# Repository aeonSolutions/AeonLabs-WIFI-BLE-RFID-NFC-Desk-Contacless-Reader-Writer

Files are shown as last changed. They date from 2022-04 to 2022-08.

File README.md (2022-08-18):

# AeonLabs WIFI BLE RFID NFC Desk Contacless Reader Writer
 This repo contains the KiCad files for the  AeonLabs WIFI BLE RFID NFC Desk Contactless Reader Writer. This PCB adds WiFi and BLE capabilities to a OEM RFID NFC reader.
Features a RGB LED and a Buzzer and is designed to be mounted on existing commercial RFID NFC reader enclosures such as the one found [here](https://s.click.aliexpress.com/e/_9wRPxz) and [here](https://www.aliexpress.com/item/1005003803301443.html?spm=a2g0o.order_list.0.0.69ba1802ydCE38)

This PCB is best suited for home automation or commercial uses for #attendances #management at a factories or offices.

*Don't forget to LIKE , SHARE and subscribe the free whatsApp group* and if you liked this PCB consider buying me a cup of coffee. Links below.




### Status
  Running. Barcode & QRcode ; RFID waiting to be tested.

If you already tested this PCB send me a message. Thank you

## Revisions
- revision 3.1
  - Added Barcode & QR code wireless receiver for handheld scanners
  -  
- revision 2.3.1
  - Design and component placement corrections 

PCB fabrication of June 2022 (reviision 3.1) was sponsored by [PCBWay](www.pcbway.com)

## Liked it ? Get a Free PCB for yourself
Send me your Device or hardware and i will design a custom PCB for it. Free of charge. Contact-me on WhatsApp or email for more info. 

|  | *Don't forget to **LIKE** , **SHARE** and **subscribe** the free chat groups* and if you downloaded one of AeonLabs's PCBs consider sponsor  any open hardware project with a donation or a cup of coffee. Links on the top, right side pane and below. |
|---|---|

<br />
<br />

## Q&A WhatsApp/Telegram Groups
|  | Subscribe to the WhatsApp or Telegram channel to get latest information about any of this KiCad projects and get help. Or simply like this kind of projects and want to stay updated with the latest research ideas and prototypes during the day and week.   |
|---|---|

<br />
<br />
<br />

## Youtube Channel
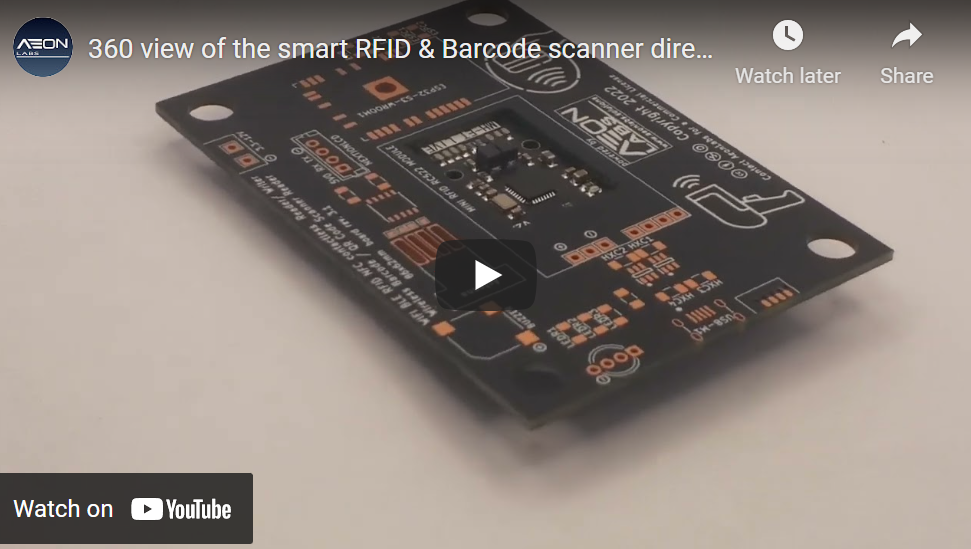
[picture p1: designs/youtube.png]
|  | Subscribe to my Youtube channel for PCB assembly instruction or any other related to Artificial Intelligence, Smart devices and robotics. Link to the channel [here](https://www.youtube.com/channel/UCAewCBpMRPGCyFc1ET5CHJw). My most recent video is .... |
|---|---|

## Fully assembled PCB
Alternatively, and if you do not want to build a PCB by yourself and like to buy one, you can do it here:

(https://www.tindie.com/stores/aeonlabs/)

The price will be around 30eur plus postage fees.
(I will also deliver the assembled PCB with all the components in place at a fair aditonal cost).

This PCB is a #direct fit #replacement of the one found on the internet at sale. For example here: https://s.click.aliexpress.com/e/_9wRPxz

#### Be supportive of my dedication and work towards technology education and buy me a coffee. Link below.

(https://www.youtube.com/watch?v=LmpYdi8Umxo)

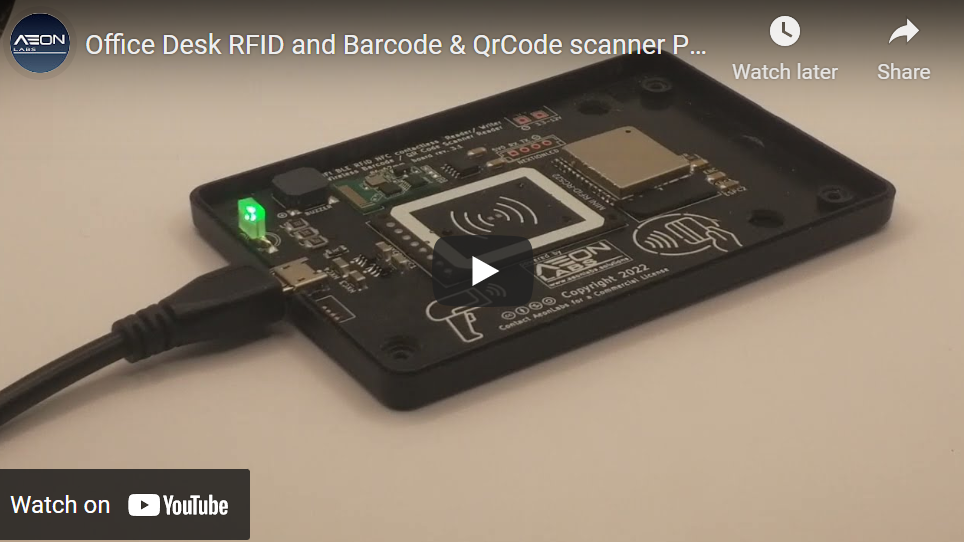
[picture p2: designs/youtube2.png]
(https://www.youtube.com/watch?v=fLvnoaH_I7A)


________________________________________________________________________________________________________________
## [Go back to main catalogue page](https://github.com/aeonSolutions/PCB-Prototyping-Catalogue)
________________________________________________________________________________________________________________

## PCB Parts list
- DC2DC converter HX4002B x2 : https://s.click.aliexpress.com/e/_Ak7IPx
- Capacitor 100nF SMD 1206 : https://s.click.aliexpress.com/e/_AVdmzr
- Capacitor 2.2uF SMD 1206 : https://s.click.aliexpress.com/e/_AVdmzr
- Resistor SMD 1206 330R x3 : https://s.click.aliexpress.com/e/_A7OXrR
- ESP32 WROOM32 x1 : https://s.click.aliexpress.com/e/_AF7N6l
- Buzzer x1: https://s.click.aliexpress.com/e/_AF7N6l
- LED RGB x1: https://s.click.aliexpress.com/e/_AccXHT
- RFID RC522 x1 (optional) : https://s.click.aliexpress.com/e/_Am0LAH

## Firmware Download 
one can use the PCB in the repository [AeonLabs-MCU-Burner-USB-to-UART-TTL](https://github.com/aeonSolutions/AeonLabs-MCU-Burner-USB-to-UART-TTL) to program the ESP32 WROOM32 MCU on this PCB.

______________________________________________________________________________________________________________________________

______________________________________________________________________________________________________________________________
### PCB Fabrication
(https://www.allpcb.com/?Mb_InviteId=79483)
(https://www.pcbway.com/setinvite.aspx?inviteid=572526)

<br />
<br />
<br />

______________________________________________________________________________________________________________________________
### License
2022 Creative Commons Attribution-NonCommercial-ShareAlike 4.0 International

https://creativecommons.org/licenses/by-nc-sa/4.0/

______________________________________________________________________________________________________________________________

<br />
<br />

### Be supportive of my dedication and work towards technology education and buy me a cup of coffee
Buy me a cup of coffee, a slice of pizza or a book to help me study, eat and think new PCB design files.

[](https://www.buymeacoffee.com/migueltomas)

<br />
<br />

### Make a donation on Paypal
Make a donation on paypal and get a TAX refund*.

(http://paypal.me/mtpsilva)

### Support all these open hardware projects and become a patreon  
Liked any of my PCB KiCad Designs? Help and Support my open work to all by becomming a LDAD Patreon.
In return I will give a free PCB design in KiCad to all patreon supporters. To learn more go to patreon.com. Link below.

(https://www.patreon.com/ldad)

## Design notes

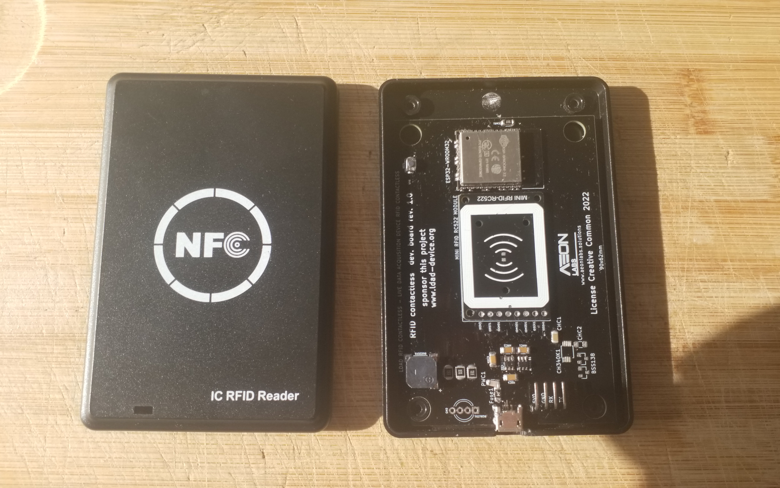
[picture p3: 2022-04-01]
designs/pcb_case.jpg

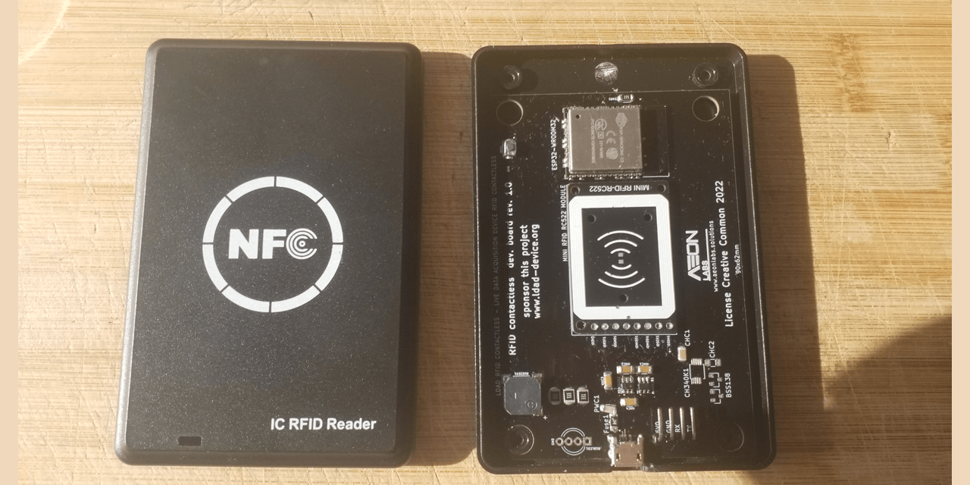
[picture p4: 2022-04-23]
designs/pcb_compressed.png

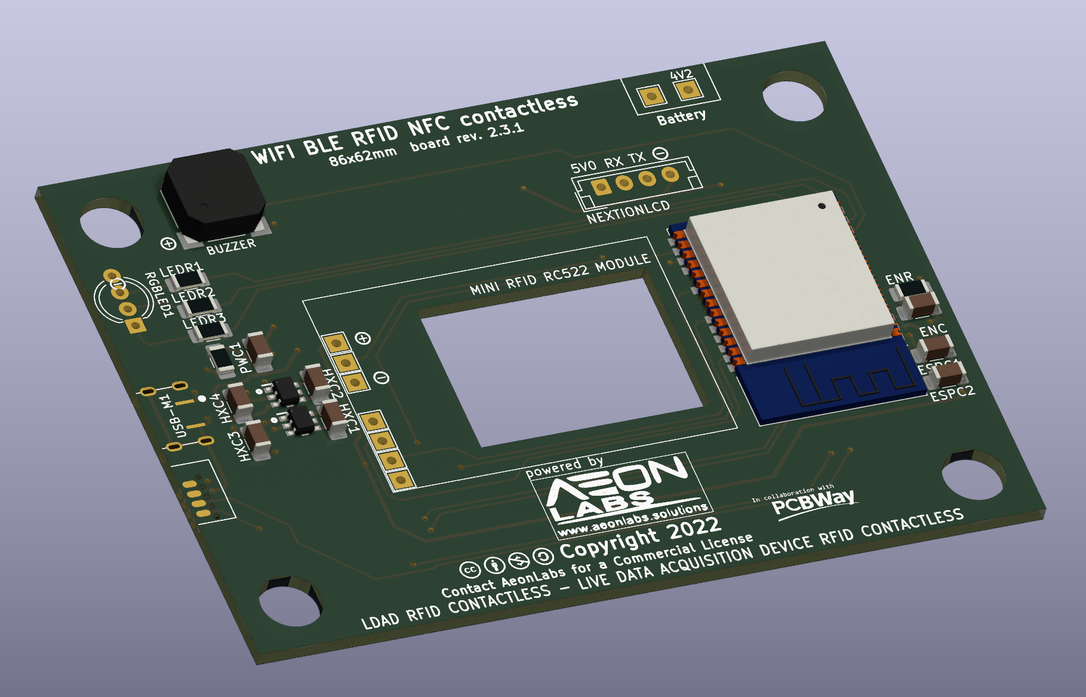
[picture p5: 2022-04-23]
designs/pcb_front.png

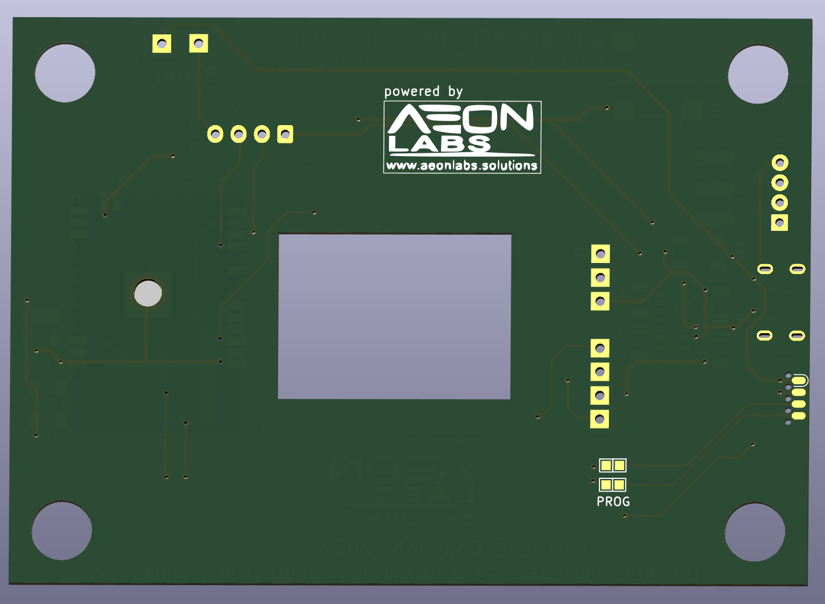
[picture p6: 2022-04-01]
designs/pcb_back.png

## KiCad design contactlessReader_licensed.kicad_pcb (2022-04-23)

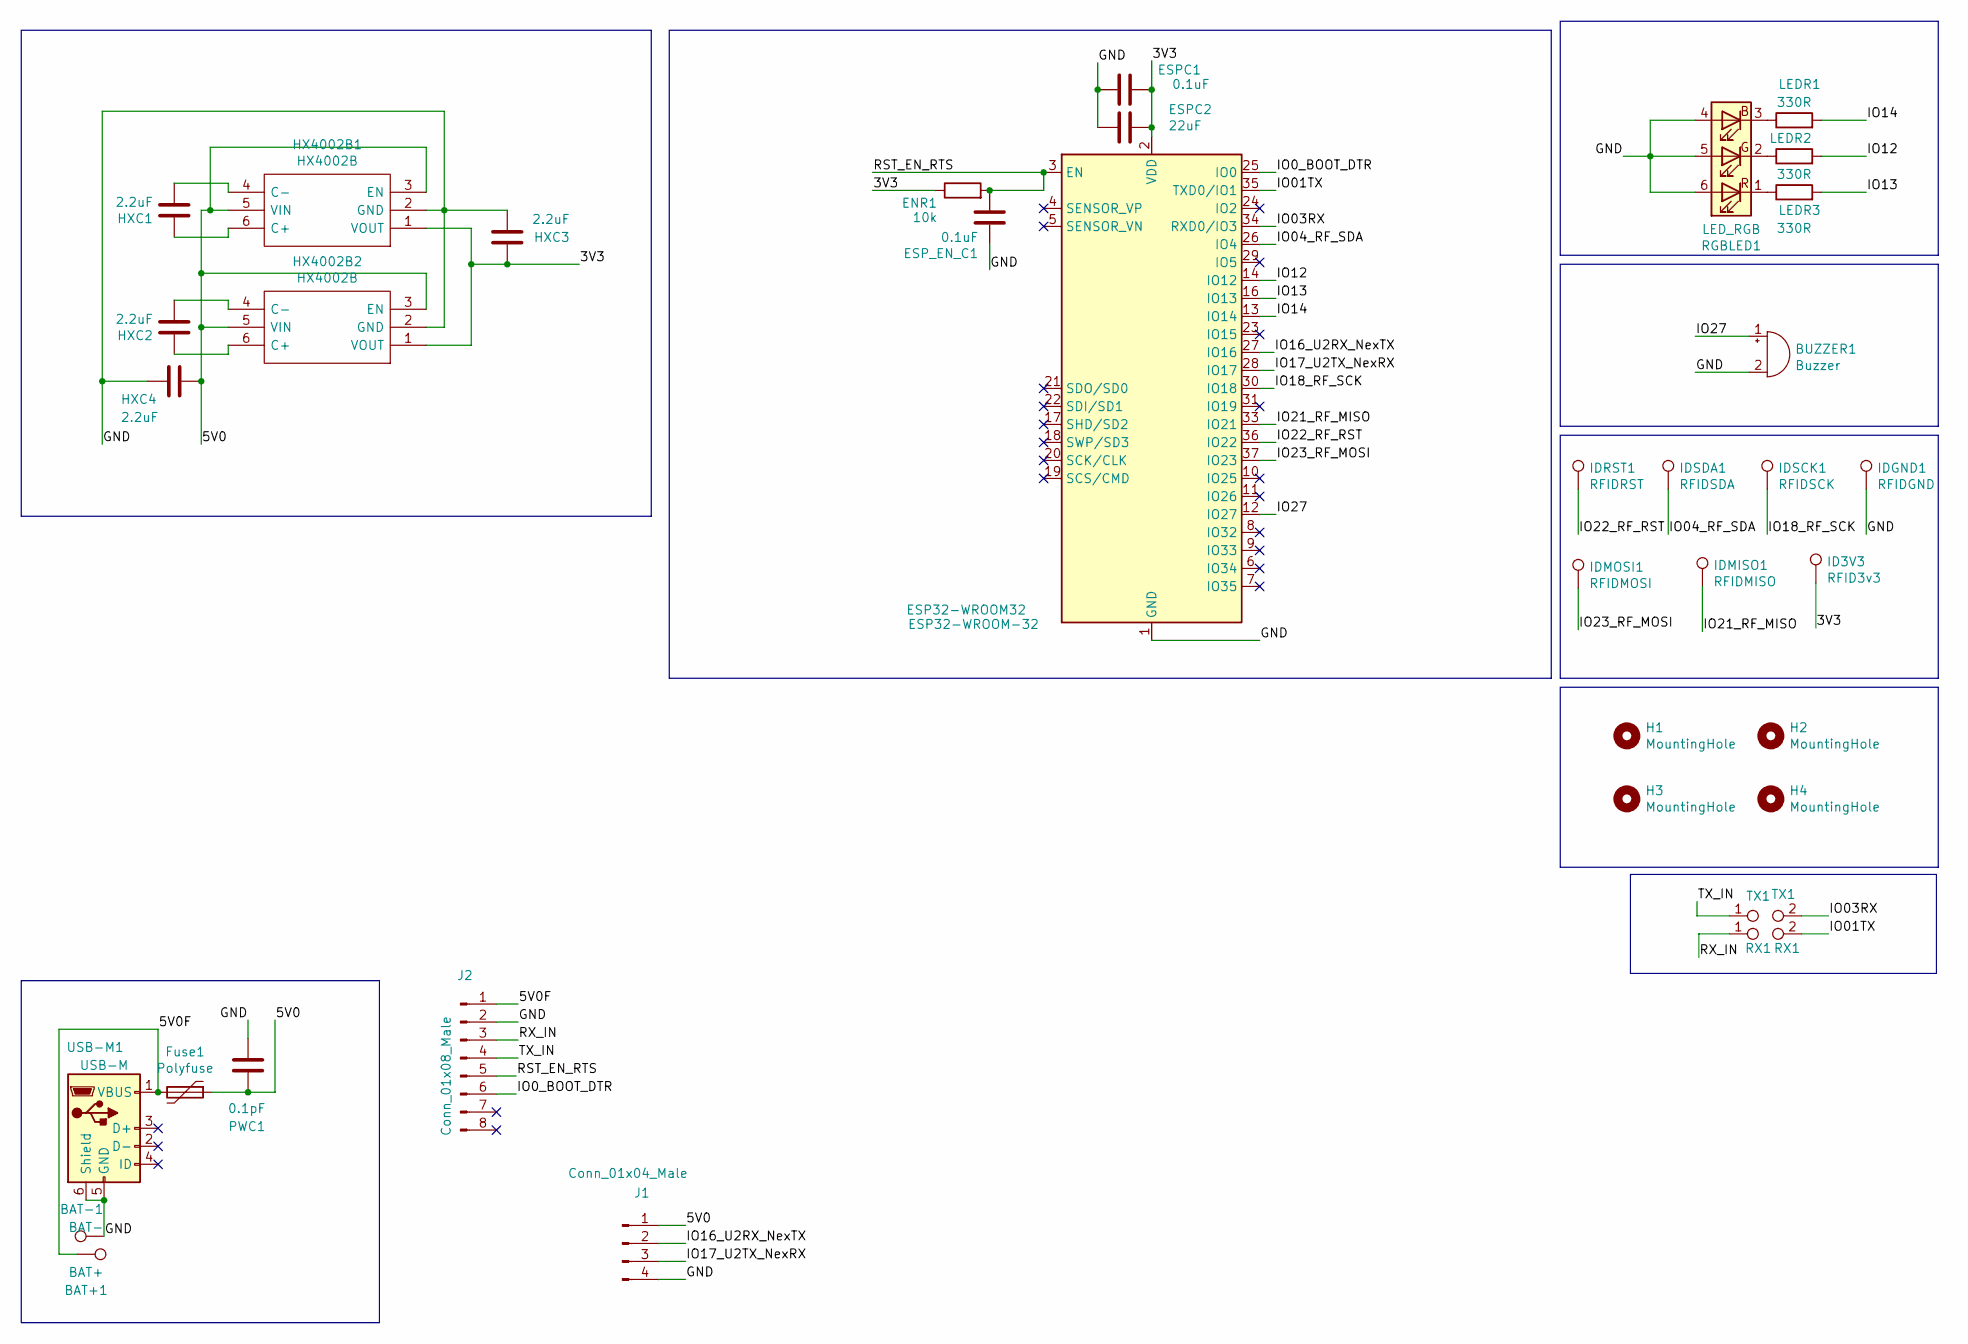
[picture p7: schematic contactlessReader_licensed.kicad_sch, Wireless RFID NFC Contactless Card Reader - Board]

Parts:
BAT+1: BAT+; TestPoint_THTPad_2.0x2.0mm_Drill1.0mm
BAT-1: BAT-; TestPoint_THTPad_2.0x2.0mm_Drill1.0mm
BUZZER1: Buzzer; MagneticBuzzer_Kobitone_254-EMB84Q-RO
ENR1: 10k; R_1206_3216Metric_Pad1.30x1.75mm_HandSolder
ESP32-WROOM32: ESP32-WROOM-32
ESPC1: 0.1uF; C_1206_3216Metric_Pad1.33x1.80mm_HandSolder
ESPC2: 22uF; C_1206_3216Metric_Pad1.33x1.80mm_HandSolder
ESP_EN_C1: 0.1uF; C_1206_3216Metric_Pad1.33x1.80mm_HandSolder
Fuse1: Polyfuse; Fuse_1206_3216Metric_Pad1.42x1.75mm_HandSolder
H1, H2, H3, H4: MountingHole; MountingHole_6.5mm
HX4002B1, HX4002B2: HX4002B; HX4002 SOT95 P280X125-6N; Manufacturer_Part_Number HX4002
HXC1, HXC2, HXC3, HXC4: 2.2uF; C_1206_3216Metric_Pad1.33x1.80mm_HandSolder
ID3V3: RFID3v3; TestPoint_THTPad_2.0x2.0mm_Drill1.0mm
IDGND1: RFIDGND; TestPoint_THTPad_2.0x2.0mm_Drill1.0mm
IDMISO1: RFIDMISO; TestPoint_THTPad_2.0x2.0mm_Drill1.0mm
IDMOSI1: RFIDMOSI; TestPoint_THTPad_2.0x2.0mm_Drill1.0mm
IDRST1: RFIDRST; TestPoint_THTPad_2.0x2.0mm_Drill1.0mm
IDSCK1: RFIDSCK; TestPoint_THTPad_2.0x2.0mm_Drill1.0mm
IDSDA1: RFIDSDA; TestPoint_THTPad_2.0x2.0mm_Drill1.0mm
J1: Conn_01x04_Male; JST_EH_B4B-EH-A_1x04_P2.50mm_Vertical
J2: Conn_01x08_Male; SOIC_clipProgSmall
LEDR1, LEDR2, LEDR3: 330R; R_1206_3216Metric_Pad1.30x1.75mm_HandSolder
PWC1: 0.1pF; C_1206_3216Metric_Pad1.33x1.80mm_HandSolder
RGBLED1: LED_RGB; LED_D5.0mm-4_RGB_Wide_Pins
RX1: RX1; TestPoint_Pad_Bridge_1.0x1.0mm
TX1: TX1; TestPoint_Pad_Bridge_1.0x1.0mm
USB-M1: USB-M; Micro_USB_pcb_socket_5pin_4weld_points

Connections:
/3V3: ENR1.1, ESP32-WROOM32.2 (VDD), ESPC1.1, ESPC2.1, HX4002B1.1 (VOUT), HX4002B2.1 (VOUT), HXC3.1, ID3V3.1
/5V0: Fuse1.1, HX4002B1.3 (EN), HX4002B1.5 (VIN), HX4002B2.3 (EN), HX4002B2.5 (VIN), HXC4.1, J1.1, PWC1.1
/5V0F: BAT+1.1, Fuse1.2, J2.1, USB-M1.1 (VBUS)
/GND: BAT-1.1, BUZZER1.2 (+), ESP32-WROOM32.1 (GND), ESP32-WROOM32.15 (GND), ESP32-WROOM32.38 (GND), ESP32-WROOM32.39 (GND), ESPC1.2, ESPC2.2, ESP_EN_C1.1, HX4002B1.2 (GND), HX4002B2.2 (GND), HXC3.2, HXC4.2, IDGND1.1, J1.4, J2.2, PWC1.2, RGBLED1.4 (BA), RGBLED1.5 (GA), RGBLED1.6 (RA), USB-M1.5 (GND), USB-M1.6 (Shield)
/IO0_BOOT_DTR: ESP32-WROOM32.25 (IO0), J2.6
/IO01TX: ESP32-WROOM32.35 (TXD0/IO1), RX1.2
/IO03RX: ESP32-WROOM32.34 (RXD0/IO3), TX1.2
/IO04_RF_SDA: ESP32-WROOM32.26 (IO4), IDSDA1.1
/IO12: ESP32-WROOM32.14 (IO12), LEDR2.2
/IO13: ESP32-WROOM32.16 (IO13), LEDR3.2
/IO14: ESP32-WROOM32.13 (IO14), LEDR1.2
/IO16_U2RX_NexTX: ESP32-WROOM32.27 (IO16), J1.2
/IO17_U2TX_NexRX: ESP32-WROOM32.28 (IO17), J1.3
/IO18_RF_SCK: ESP32-WROOM32.30 (IO18), IDSCK1.1
/IO21_RF_MISO: ESP32-WROOM32.33 (IO21), IDMISO1.1
/IO22_RF_RST: ESP32-WROOM32.36 (IO22), IDRST1.1
/IO23_RF_MOSI: ESP32-WROOM32.37 (IO23), IDMOSI1.1
/IO27: BUZZER1.1 (-), ESP32-WROOM32.12 (IO27)
/RST_EN_RTS: ENR1.2, ESP32-WROOM32.3 (EN), ESP_EN_C1.2, J2.5
/RX_IN: J2.3, RX1.1
/TX_IN: J2.4, TX1.1
unnamed: HX4002B1.4 (C-), HXC1.2
unnamed: HX4002B1.6 (C+), HXC1.1
unnamed: HX4002B2.4 (C-), HXC2.2
unnamed: HX4002B2.6 (C+), HXC2.1
unnamed: LEDR1.1, RGBLED1.3 (BK)
unnamed: LEDR2.1, RGBLED1.2 (GK)
unnamed: LEDR3.1, RGBLED1.1 (RK)

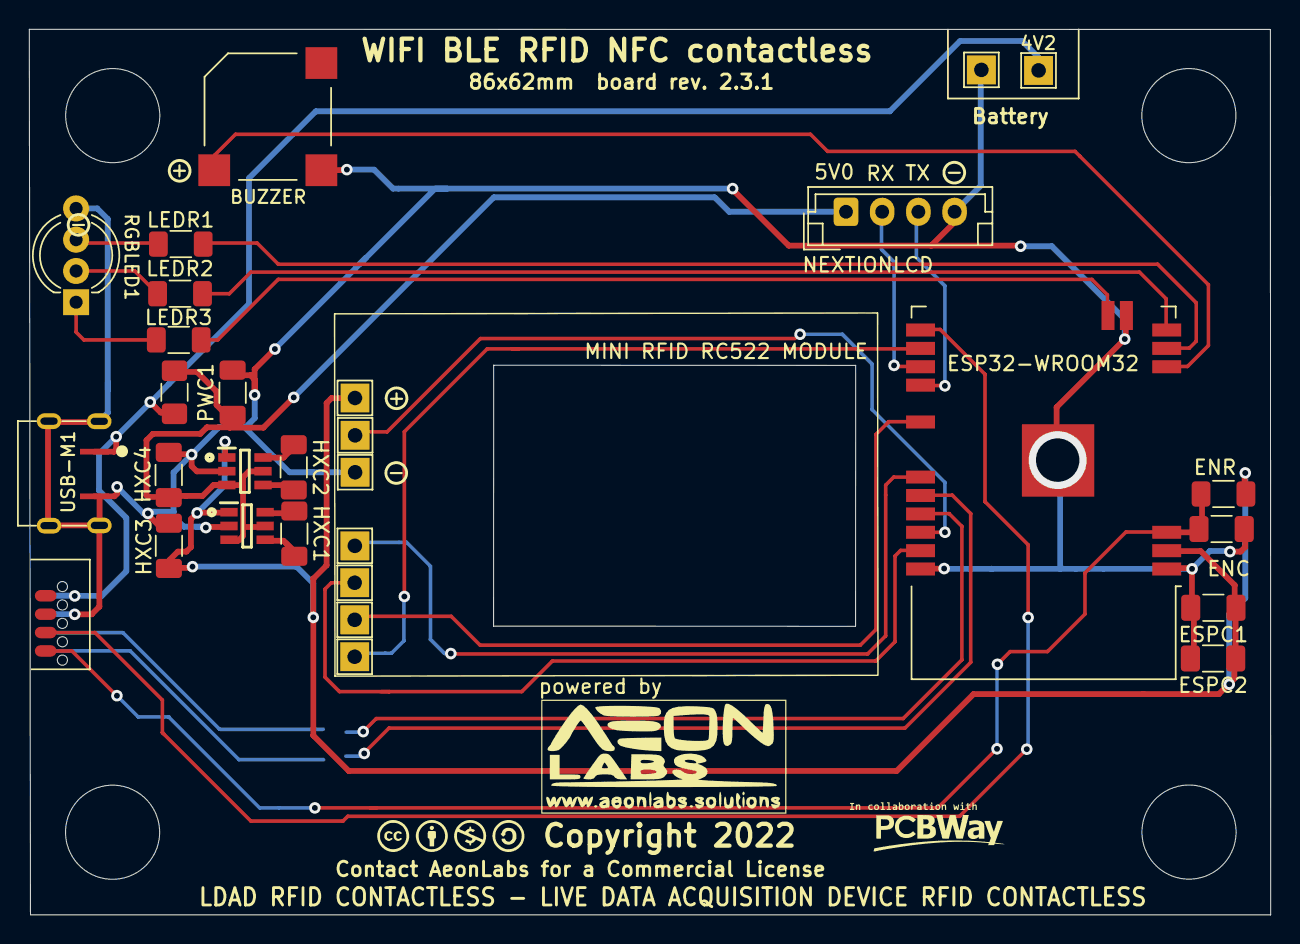
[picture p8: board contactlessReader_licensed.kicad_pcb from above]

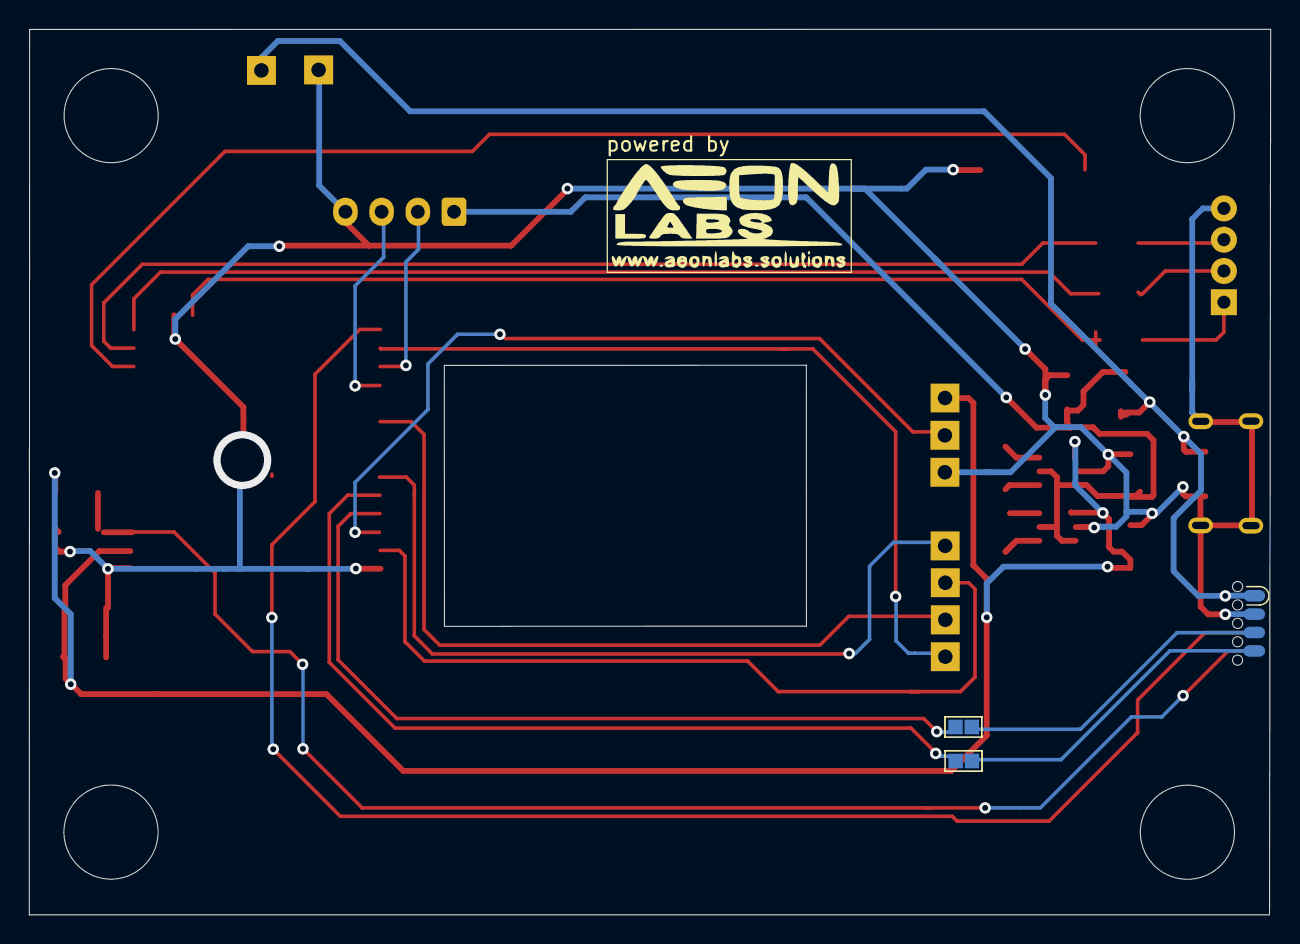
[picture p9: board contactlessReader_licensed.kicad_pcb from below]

Board: 2 copper layers, 85.7 x 61.2 mm, 36 parts (3 on the bottom side), 28 nets.

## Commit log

2022-04-01 kicad files
    [contactlessReader_licensed.kicad_pcb, contactlessReader_licensed.kicad_sch]
2022-04-23 rev. 2.3.1
    [contactlessReader_licensed.kicad_pcb, contactlessReader_licensed.kicad_sch]

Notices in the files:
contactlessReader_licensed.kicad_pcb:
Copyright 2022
